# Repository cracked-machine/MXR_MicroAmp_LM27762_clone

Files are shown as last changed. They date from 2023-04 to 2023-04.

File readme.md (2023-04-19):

## LM27762 Eval Board with OPAMP test circuit.

This is an eval board for the Texas Instruments [LM27762](hw/datasheets/lm27762.pdf) charge pump IC. It provides a +/-5V regulated split rail from +5.5V input.

To view the schematic click [here](hw/mxr_microamp.pdf).

A render of the board layout is below: 

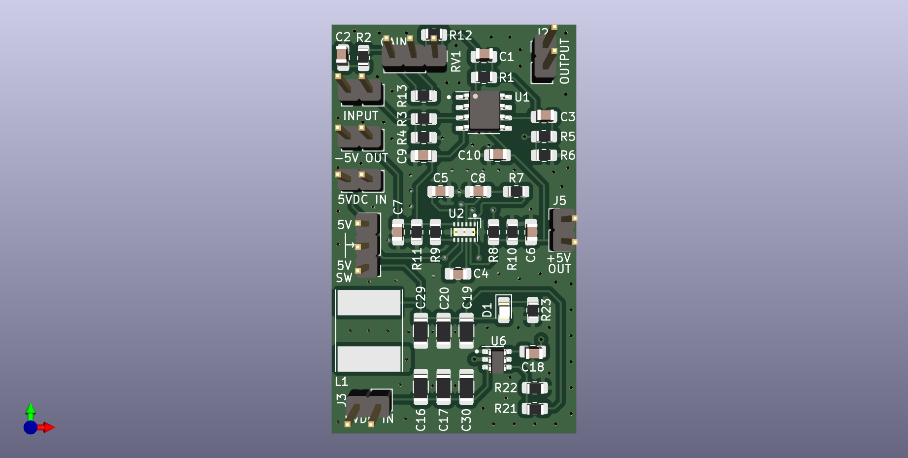
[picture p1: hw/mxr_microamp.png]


### OpAmp test circuit

The board comes with an additional OpAmp test circuit based on the popular [MXR MicroAmp](https://www.electrosmash.com/mxr-microamp) "boost" guitar pedal. 

The circuit will accept a +9V power input, so this board can be used as a fully functional MicroAmp clone pedal. 

A reverse audio taper 500K pot should be attached to the `gain` header. If reverse audio cannot be obtained then biasing the potentiometer is possible. See schematic for details.

Wiring for the bypass switch should be done [off-board using a 3PDT switch](https://madbeanpedals.com/tutorials/downloads/MBP_FootswitchWiring.pdf).

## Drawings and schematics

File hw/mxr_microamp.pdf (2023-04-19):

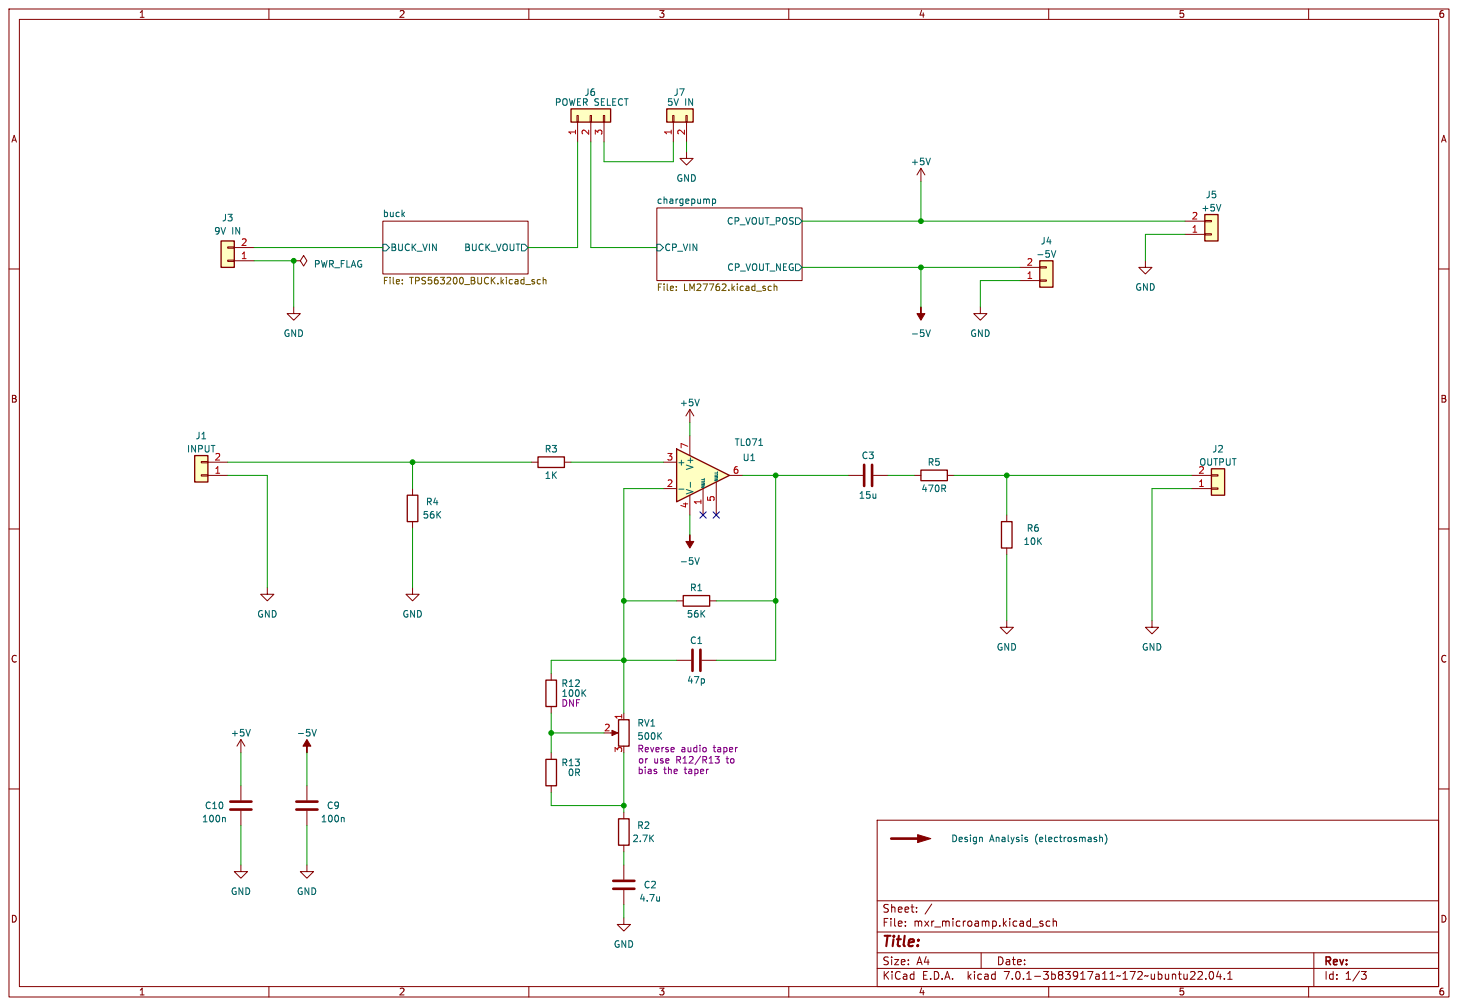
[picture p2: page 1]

bias the taper GND

Id: 1/3 Title: File: mxr_microamp.kicad_sch Sheet: /

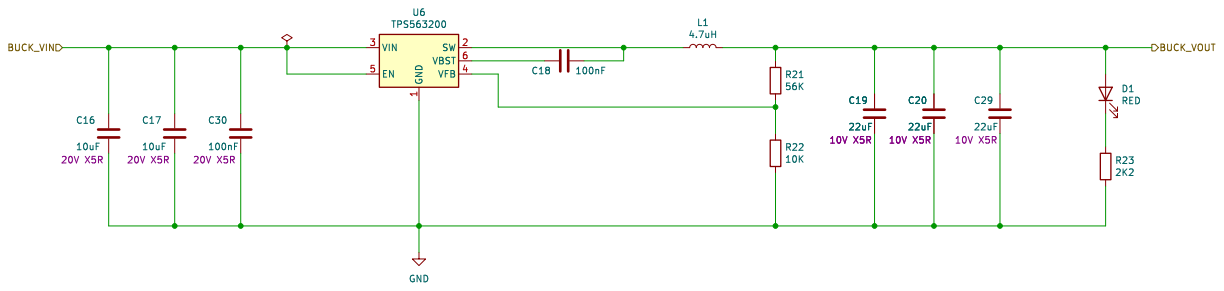
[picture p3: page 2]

1 SW 2 VIN 3 VFB 4 EN 5 VBST 6 U6 TPS563200 BUCK_VIN BUCK_VOUT C19

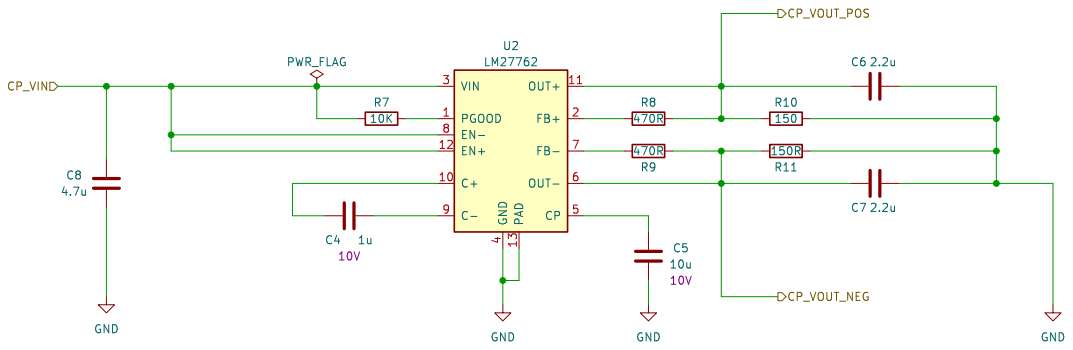
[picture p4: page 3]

4 CP 5 OUT- 6 FB- 7 EN- 8 C- 9 U2
LM27762 GND

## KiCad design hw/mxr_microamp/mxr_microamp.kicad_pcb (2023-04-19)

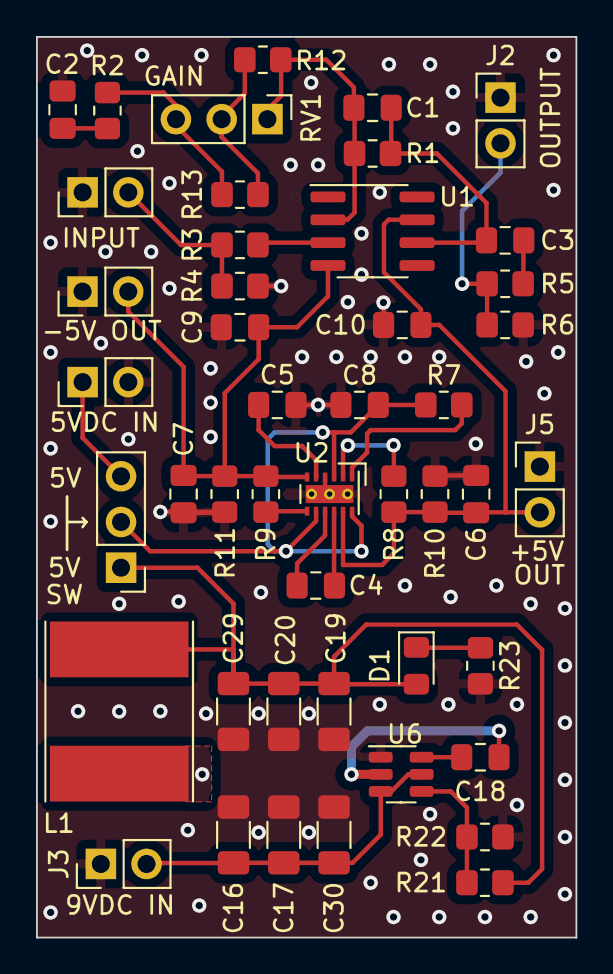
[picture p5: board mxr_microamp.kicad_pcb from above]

Board: 2 copper layers, 30.0 x 50.0 mm, 46 parts (0 on the bottom side), 26 nets.

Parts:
C1: 47p; C_0805_2012Metric_Pad1.18x1.45mm_HandSolder
C2, C8: 4.7u; C_0805_2012Metric_Pad1.18x1.45mm_HandSolder
C3: 15u; C_0805_2012Metric_Pad1.18x1.45mm_HandSolder
C4: 1u; C_0805_2012Metric_Pad1.18x1.45mm_HandSolder
C5: 10u; C_0805_2012Metric_Pad1.18x1.45mm_HandSolder
C6, C7: 2.2u; C_0805_2012Metric_Pad1.18x1.45mm_HandSolder
C9, C10: 100n; C_0805_2012Metric_Pad1.18x1.45mm_HandSolder
C16, C17: 10uF; R_1206_3216Metric_Pad1.30x1.75mm_HandSolder
C18: 100nF; C_0805_2012Metric_Pad1.18x1.45mm_HandSolder
C19, C20, C29: 22uF; R_1206_3216Metric_Pad1.30x1.75mm_HandSolder
C30: 100nF; R_1206_3216Metric_Pad1.30x1.75mm_HandSolder
D1: RED; LED_0805_2012Metric_Pad1.15x1.40mm_HandSolder
J1: INPUT; PinHeader_1x02_P2.54mm_Vertical
J2: OUTPUT; PinHeader_1x02_P2.54mm_Vertical
J3: 9V IN; PinHeader_1x02_P2.54mm_Vertical
J4: -5V; PinHeader_1x02_P2.54mm_Vertical
J5: +5V; PinHeader_1x02_P2.54mm_Vertical
J6: POWER SELECT; PinHeader_1x03_P2.54mm_Vertical
J7: 5V IN; PinHeader_1x02_P2.54mm_Vertical
L1: 4.7uH; L_Taiyo-Yuden_NR-80xx_HandSoldering
R1, R4, R21: 56K; R_0805_2012Metric_Pad1.20x1.40mm_HandSolder
R2: 2.7K; R_0805_2012Metric_Pad1.20x1.40mm_HandSolder
R3: 1K; R_0805_2012Metric_Pad1.20x1.40mm_HandSolder
R5, R8, R9: 470R; R_0805_2012Metric_Pad1.20x1.40mm_HandSolder
R6, R7, R22: 10K; R_0805_2012Metric_Pad1.20x1.40mm_HandSolder
R10: 150; R_0805_2012Metric_Pad1.20x1.40mm_HandSolder
R11: 150R; R_0805_2012Metric_Pad1.20x1.40mm_HandSolder
R12: 100K; R_0805_2012Metric_Pad1.20x1.40mm_HandSolder
R13: 0R; R_0805_2012Metric_Pad1.20x1.40mm_HandSolder
R23: 2K2; R_0805_2012Metric_Pad1.20x1.40mm_HandSolder
RV1: 500K; PinHeader_1x03_P2.54mm_Vertical
U1: TL071; SOIC-8_3.9x4.9mm_P1.27mm
U2: LM27762; WSON-12-1EP_3x2mm_P0.5mm_EP1x2.65_ThermalVias
U6: TPS563200; SOT-23-6

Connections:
+5V: C6.1, C10.2, J5.2, R8.2, R10.1, U1.7 (V+), U2.11 (OUT+)
-5V: C7.1, C9.2, J4.2, R9.2, R11.1, U1.4 (V-), U2.6 (OUT-)
/buck/BUCK_VIN: C16.1, C17.1, C30.1, J3.2, U6.3 (VIN), U6.5 (EN)
/buck/BUCK_VOUT: C19.1, C20.1, C29.1, D1.2 (A), J6.1, L1.2, R21.1
/chargepump/CP_VIN: C8.1, J6.2, R7.1, U2.3 (VIN), U2.8 (EN-), U2.12 (EN+)
GND: C2.1, C5.2, C6.2, C7.2, C8.2, C9.1, C10.1, C16.2, C17.2, C19.2, C20.2, C29.2, C30.2, J1.1, J2.1, J3.1, J4.1, J5.1, J7.2, R4.1, R6.1, R10.2, R11.2, R22.2, R23.2, U2.4 (GND), U2.13 (PAD), U6.1 (GND)
unnamed: C1.2, C3.1, R1.2, U1.6
unnamed: C2.2, R2.1
unnamed: C3.2, R5.1
unnamed: D1.1 (K), R23.1
unnamed: J1.2, R3.1, R4.2
unnamed: J2.2, R5.2, R6.2
unnamed: J6.3, J7.1
unnamed: R12.1, R13.2, RV1.2
unnamed: R2.2, R13.1, RV1.3
unnamed: R3.2, U1.3 (+)
unnamed: C1.1, R1.1, R12.2, RV1.1, U1.2 (-)
unnamed: C4.2, U2.10 (C+)
unnamed: C4.1, U2.9 (C-)
unnamed: C5.1, U2.5 (CP)
unnamed: R8.1, U2.2 (FB+)
unnamed: R9.1, U2.7 (FB-)
unnamed: R7.2, U2.1 (PGOOD)
unnamed: C18.2, L1.1, U6.2 (SW)
unnamed: C18.1, U6.6 (VBST)
unnamed: R21.2, R22.1, U6.4 (VFB)
